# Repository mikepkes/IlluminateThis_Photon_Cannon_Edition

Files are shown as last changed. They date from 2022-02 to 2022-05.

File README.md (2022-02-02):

The Illuminate This "Photon Cannon Edition" is the 3rd production in the "Illuminate This" series.

Illuminate This boards are intended to be useful lighting boards for incorporating into your own projects.

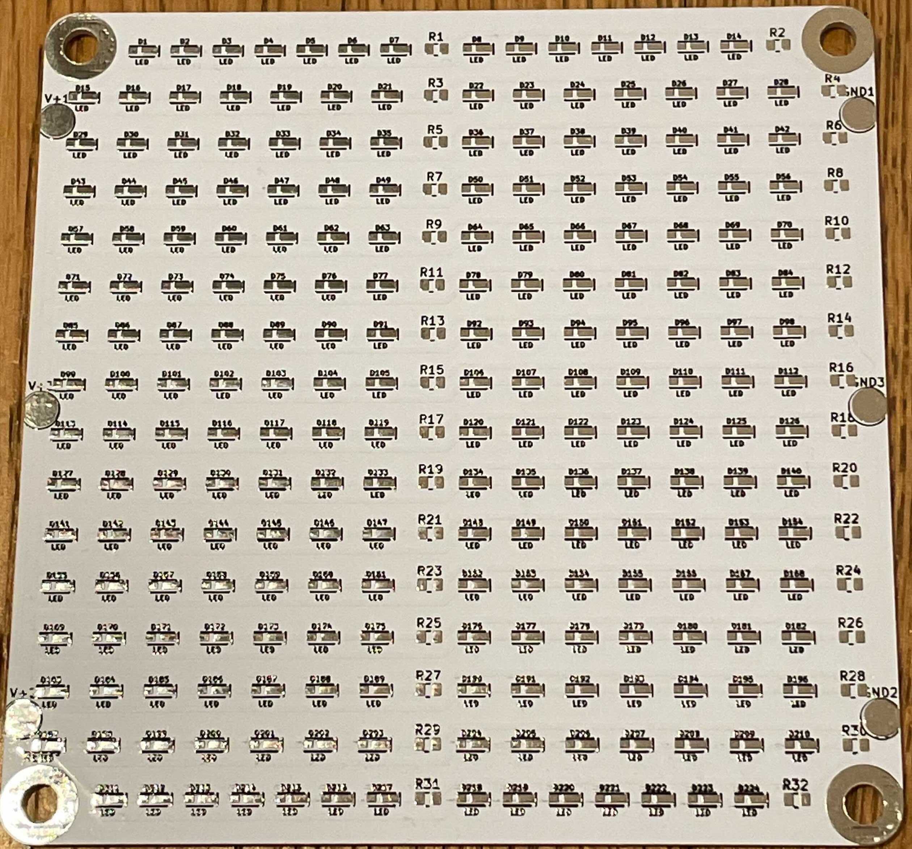
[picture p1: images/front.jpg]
Front PCB Render

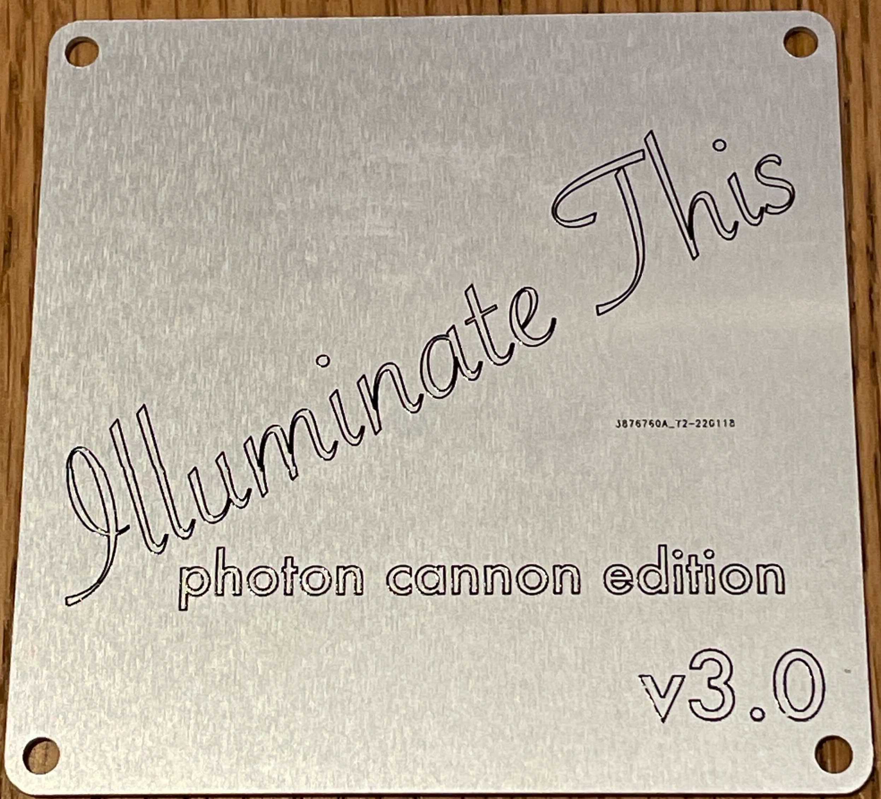
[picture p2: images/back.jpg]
Back PCB Render


Illuminate This boards are intended to provde:
* A large lighting area made of many LEDs
* Utilize component surplus at VHS
* Be easy to solder for people new to SMD components
* Customizable Lighitng, Remove Rows you don't want!

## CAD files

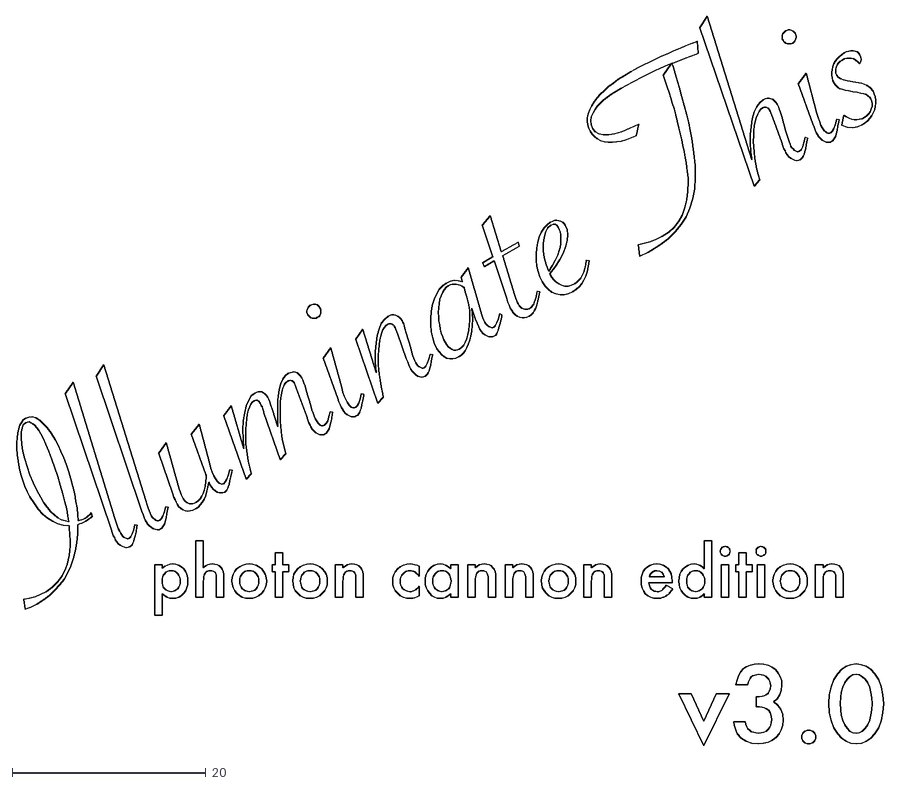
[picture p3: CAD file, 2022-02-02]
back_art.dxf
89.4 x 75.3

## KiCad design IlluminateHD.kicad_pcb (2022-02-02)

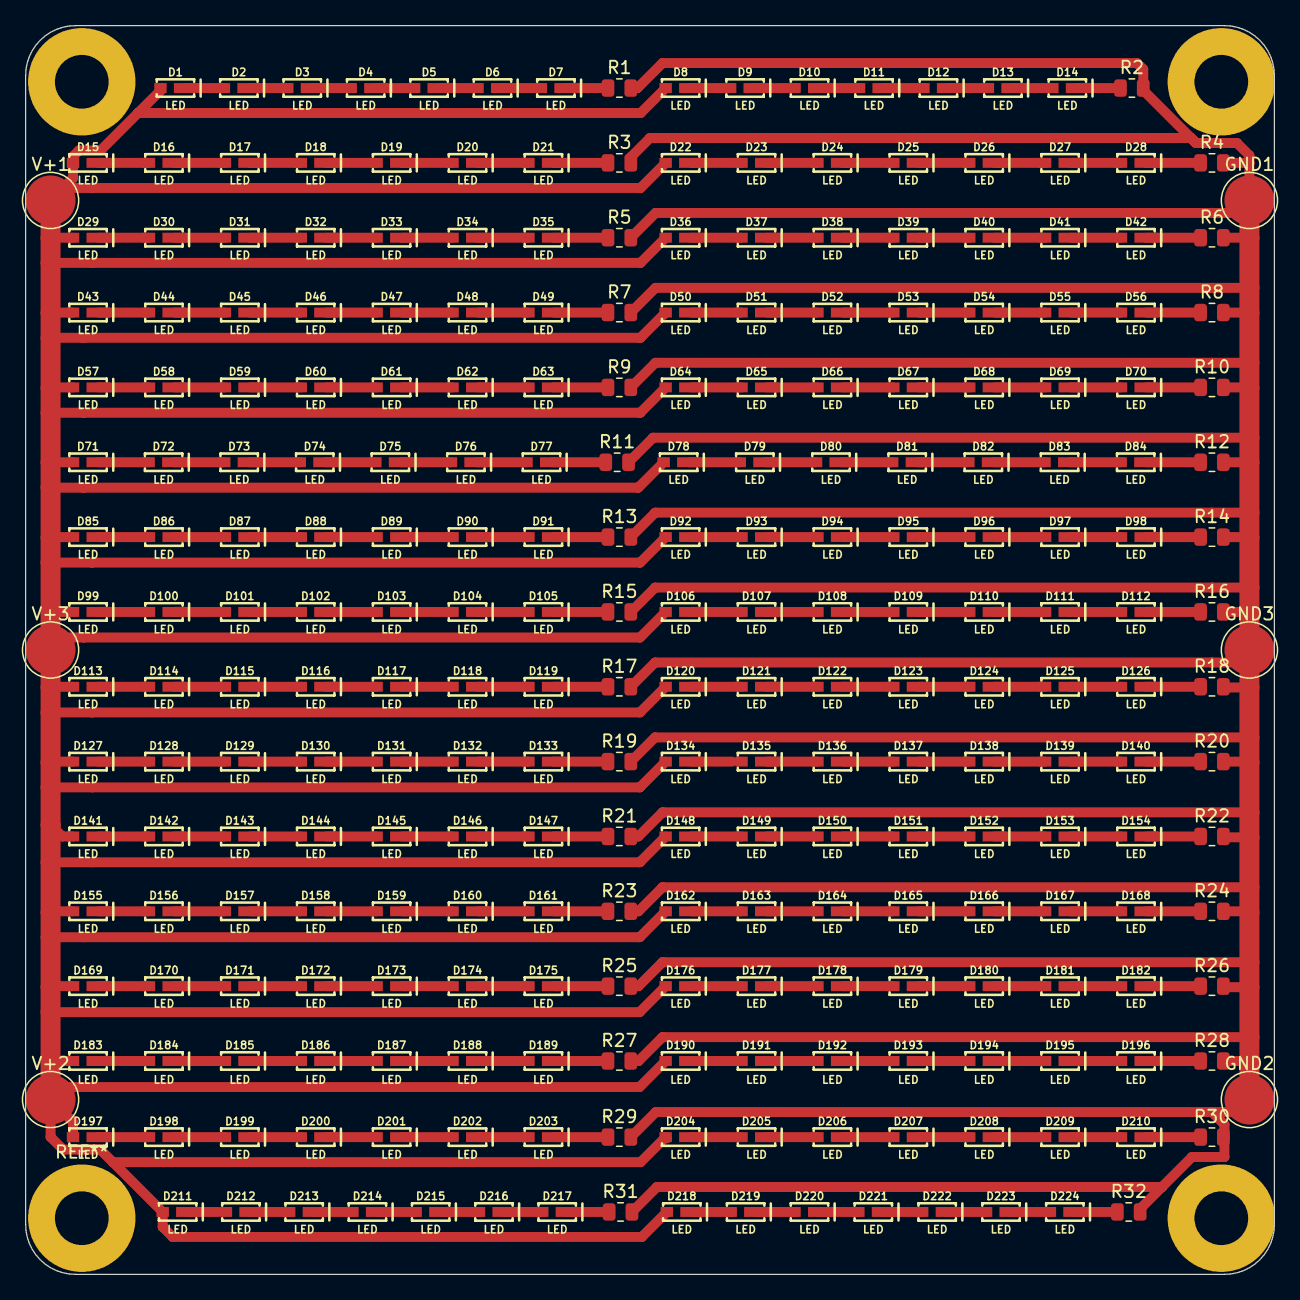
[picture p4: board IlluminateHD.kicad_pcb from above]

Board: 2 copper layers, 100.0 x 100.0 mm, 262 parts (0 on the bottom side), 226 nets.

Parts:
D1, D2, D3, D4, D5, D6, D7, D8, D9, D10, D11, D12, D13, D14, D15, D16, D17, D18, D19, D20, D21, D22, D23, D24, D25, D26, D27, D28, D29, D30, D31, D32, D33, D34, D35, D36, D37, D38, D39, D40, D41, D42, D43, D44, D45, D46, D47, D48, D49, D50, D51, D52, D53, D54, D55, D56, D57, D58, D59, D60, D61, D62, D63, D64, D65, D66, D67, D68, D69, D70, D71, D72, D73, D74, D75, D76, D77, D78, D79, D80, D81, D82, D83, D84, D85, D86, D87, D88, D89, D90, D91, D92, D93, D94, D95, D96, D97, D98, D99, D100, D101, D102, D103, D104, D105, D106, D107, D108, D109, D110, D111, D112, D113, D114, D115, D116, D117, D118, D119, D120, D121, D122, D123, D124, D125, D126, D127, D128, D129, D130, D131, D132, D133, D134, D135, D136, D137, D138, D139, D140, D141, D142, D143, D144, D145, D146, D147, D148, D149, D150, D151, D152, D153, D154, D155, D156, D157, D158, D159, D160, D161, D162, D163, D164, D165, D166, D167, D168, D169, D170, D171, D172, D173, D174, D175, D176, D177, D178, D179, D180, D181, D182, D183, D184, D185, D186, D187, D188, D189, D190, D191, D192, D193, D194, D195, D196, D197, D198, D199, D200, D201, D202, D203, D204, D205, D206, D207, D208, D209, D210, D211, D212, D213, D214, D215, D216, D217, D218, D219, D220, D221, D222, D223, D224: LED; SUPER_BRIGHT_SMD_LED_3014
GND1, GND2, GND3: TestPoint; TestPoint_Pad_D4.0mm
R1, R2, R3, R4, R5, R6, R7, R8, R9, R10, R11, R12, R13, R14, R15, R16, R17, R18, R19, R20, R21, R22, R23, R24, R25, R26, R27, R28, R29, R30, R31, R32: R_US; R_0805_2012Metric
V+1, V+2, V+3: TestPoint; TestPoint_Pad_D4.0mm

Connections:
+24V: D1.A, D8.A, D15.A, D22.A, D29.A, D36.A, D43.A, D50.A, D57.A, D64.A, D71.A, D78.A, D85.A, D92.A, D99.A, D106.A, D113.A, D120.A, D127.A, D134.A, D141.A, D148.A, D155.A, D162.A, D169.A, D176.A, D183.A, D190.A, D197.A, D204.A, D211.A, D218.A, V+1.1, V+2.1, V+3.1
GND: GND1.1, GND2.1, GND3.1, R1.2, R2.2, R3.2, R4.2, R5.2, R6.2, R7.2, R8.2, R9.2, R10.2, R11.2, R12.2, R13.2, R14.2, R15.2, R16.2, R17.2, R18.2, R19.2, R20.2, R21.2, R22.2, R23.2, R24.2, R25.2, R26.2, R27.2, R28.2, R29.2, R30.2, R31.2, R32.2
unnamed: D1.C, D2.A
unnamed: D2.C, D3.A
unnamed: D3.C, D4.A
unnamed: D4.C, D5.A
unnamed: D5.C, D6.A
unnamed: D6.C, D7.A
unnamed: D7.C, R1.1
unnamed: D8.C, D9.A
unnamed: D9.C, D10.A
unnamed: D10.C, D11.A
unnamed: D11.C, D12.A
unnamed: D12.C, D13.A
unnamed: D13.C, D14.A
unnamed: D14.C, R2.1
unnamed: D15.C, D16.A
unnamed: D16.C, D17.A
unnamed: D17.C, D18.A
unnamed: D18.C, D19.A
unnamed: D19.C, D20.A
unnamed: D20.C, D21.A
unnamed: D21.C, R3.1
unnamed: D22.C, D23.A
unnamed: D23.C, D24.A
unnamed: D24.C, D25.A
unnamed: D25.C, D26.A
unnamed: D26.C, D27.A
unnamed: D27.C, D28.A
unnamed: D28.C, R4.1
unnamed: D29.C, D30.A
unnamed: D30.C, D31.A
unnamed: D31.C, D32.A
unnamed: D32.C, D33.A
unnamed: D33.C, D34.A
unnamed: D34.C, D35.A
unnamed: D35.C, R5.1
unnamed: D36.C, D37.A
unnamed: D37.C, D38.A
unnamed: D38.C, D39.A
unnamed: D39.C, D40.A
unnamed: D40.C, D41.A
unnamed: D41.C, D42.A
unnamed: D42.C, R6.1
unnamed: D43.C, D44.A
unnamed: D44.C, D45.A
unnamed: D45.C, D46.A
unnamed: D46.C, D47.A
unnamed: D47.C, D48.A
unnamed: D48.C, D49.A
unnamed: D49.C, R7.1
unnamed: D50.C, D51.A
unnamed: D51.C, D52.A
unnamed: D52.C, D53.A
unnamed: D53.C, D54.A
unnamed: D54.C, D55.A
unnamed: D55.C, D56.A
unnamed: D56.C, R8.1
unnamed: D57.C, D58.A
unnamed: D58.C, D59.A
unnamed: D59.C, D60.A
unnamed: D60.C, D61.A
unnamed: D61.C, D62.A
unnamed: D62.C, D63.A
unnamed: D63.C, R9.1
unnamed: D64.C, D65.A
unnamed: D65.C, D66.A
unnamed: D66.C, D67.A
unnamed: D67.C, D68.A
unnamed: D68.C, D69.A
unnamed: D69.C, D70.A
unnamed: D70.C, R10.1
unnamed: D71.C, D72.A
unnamed: D72.C, D73.A
unnamed: D73.C, D74.A
unnamed: D74.C, D75.A
unnamed: D75.C, D76.A
unnamed: D76.C, D77.A
unnamed: D77.C, R11.1
unnamed: D78.C, D79.A
unnamed: D79.C, D80.A
unnamed: D80.C, D81.A
unnamed: D81.C, D82.A
unnamed: D82.C, D83.A
unnamed: D83.C, D84.A
unnamed: D84.C, R12.1
unnamed: D85.C, D86.A
unnamed: D86.C, D87.A
unnamed: D87.C, D88.A
unnamed: D88.C, D89.A
unnamed: D89.C, D90.A
unnamed: D90.C, D91.A
unnamed: D91.C, R13.1
unnamed: D92.C, D93.A
unnamed: D93.C, D94.A
unnamed: D94.C, D95.A
unnamed: D95.C, D96.A
unnamed: D96.C, D97.A
unnamed: D97.C, D98.A
unnamed: D98.C, R14.1
unnamed: D99.C, D100.A
unnamed: D100.C, D101.A
unnamed: D101.C, D102.A
unnamed: D102.C, D103.A
unnamed: D103.C, D104.A
unnamed: D104.C, D105.A
unnamed: D105.C, R15.1
unnamed: D106.C, D107.A
unnamed: D107.C, D108.A
unnamed: D108.C, D109.A
unnamed: D109.C, D110.A
unnamed: D110.C, D111.A
unnamed: D111.C, D112.A
unnamed: D112.C, R16.1
unnamed: D113.C, D114.A
unnamed: D114.C, D115.A
unnamed: D115.C, D116.A
unnamed: D116.C, D117.A
unnamed: D117.C, D118.A
unnamed: D118.C, D119.A
unnamed: D119.C, R17.1
unnamed: D120.C, D121.A
unnamed: D121.C, D122.A
unnamed: D122.C, D123.A
unnamed: D123.C, D124.A
unnamed: D124.C, D125.A
unnamed: D125.C, D126.A
unnamed: D126.C, R18.1
unnamed: D127.C, D128.A
unnamed: D128.C, D129.A
unnamed: D129.C, D130.A
unnamed: D130.C, D131.A
unnamed: D131.C, D132.A
unnamed: D132.C, D133.A
unnamed: D133.C, R19.1
unnamed: D134.C, D135.A
unnamed: D135.C, D136.A
unnamed: D136.C, D137.A
unnamed: D137.C, D138.A
unnamed: D138.C, D139.A
unnamed: D139.C, D140.A
unnamed: D140.C, R20.1
unnamed: D141.C, D142.A
unnamed: D142.C, D143.A
unnamed: D143.C, D144.A
unnamed: D144.C, D145.A
unnamed: D145.C, D146.A
unnamed: D146.C, D147.A
unnamed: D147.C, R21.1
unnamed: D148.C, D149.A
unnamed: D149.C, D150.A
unnamed: D150.C, D151.A
unnamed: D151.C, D152.A
unnamed: D152.C, D153.A
unnamed: D153.C, D154.A
unnamed: D154.C, R22.1
unnamed: D155.C, D156.A
unnamed: D156.C, D157.A
unnamed: D157.C, D158.A
unnamed: D158.C, D159.A
unnamed: D159.C, D160.A
unnamed: D160.C, D161.A
unnamed: D161.C, R23.1
unnamed: D162.C, D163.A
unnamed: D163.C, D164.A
unnamed: D164.C, D165.A
unnamed: D165.C, D166.A
unnamed: D166.C, D167.A
unnamed: D167.C, D168.A
unnamed: D168.C, R24.1
unnamed: D169.C, D170.A
unnamed: D170.C, D171.A
unnamed: D171.C, D172.A
unnamed: D172.C, D173.A
unnamed: D173.C, D174.A
unnamed: D174.C, D175.A
unnamed: D175.C, R25.1
unnamed: D176.C, D177.A
unnamed: D177.C, D178.A
unnamed: D178.C, D179.A
unnamed: D179.C, D180.A
unnamed: D180.C, D181.A
unnamed: D181.C, D182.A
unnamed: D182.C, R26.1
unnamed: D183.C, D184.A
unnamed: D184.C, D185.A
unnamed: D185.C, D186.A
unnamed: D186.C, D187.A
unnamed: D187.C, D188.A
unnamed: D188.C, D189.A
unnamed: D189.C, R27.1
unnamed: D190.C, D191.A
unnamed: D191.C, D192.A
unnamed: D192.C, D193.A
unnamed: D193.C, D194.A
unnamed: D194.C, D195.A
unnamed: D195.C, D196.A
unnamed: D196.C, R28.1
unnamed: D197.C, D198.A
unnamed: D198.C, D199.A
unnamed: D199.C, D200.A
unnamed: D200.C, D201.A
unnamed: D201.C, D202.A
unnamed: D202.C, D203.A
unnamed: D203.C, R29.1
unnamed: D204.C, D205.A
unnamed: D205.C, D206.A
unnamed: D206.C, D207.A
unnamed: D207.C, D208.A
unnamed: D208.C, D209.A
unnamed: D209.C, D210.A
unnamed: D210.C, R30.1
unnamed: D211.C, D212.A
unnamed: D212.C, D213.A
unnamed: D213.C, D214.A
unnamed: D214.C, D215.A
unnamed: D215.C, D216.A
unnamed: D216.C, D217.A
unnamed: D217.C, R31.1
unnamed: D218.C, D219.A
unnamed: D219.C, D220.A
unnamed: D220.C, D221.A
unnamed: D221.C, D222.A
unnamed: D222.C, D223.A
unnamed: D223.C, D224.A
unnamed: D224.C, R32.1

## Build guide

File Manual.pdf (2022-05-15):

# Illuminate This

# Photon Cannon Edition (v3.0)

Welcome to the instruction manual for the Illuminate This: Photon Cannon Edition, the third edition of the Illuminate This board.

The “Illuminate This” series was born at the Vancouver Hackspace, when millions upon millions of white SMD LEDs were donated and there was no plan for them. This board provides a nice way of creating area-like lights that can be used as back-lighting, or just really really big flat bulbs.
The Illuminate This: Photon Cannon Edition tech specs are as follows:

## Building the Photon Cannon

It is recommended to use the provided solder stencil to build the Illuminate This boards and use the solder oven; it is not recommended to hand-solder LEDs, especially on aluminum boards, as it will be exceedingly difficult to not damage the LEDs while getting the pad hot enough to flow.

Name | The Illuminate This: Photon Cannon Edition
Board Version | v3.0
Width | 100mm
Height | 100mm
Supply Voltage | 24v
Supply Maximum Current | 6.2 Amps (at 20ma configuration, fully populated)
LED Grouping | 7 LEDs, 1 Current Limiting Resistor
Maximum LEDs | 224
Board Material | Aluminum or FR4
Mounting Holes | M4 x 4
LED Form Factor | 3014 SMD
Resistor Form Factor | 0805 SMD

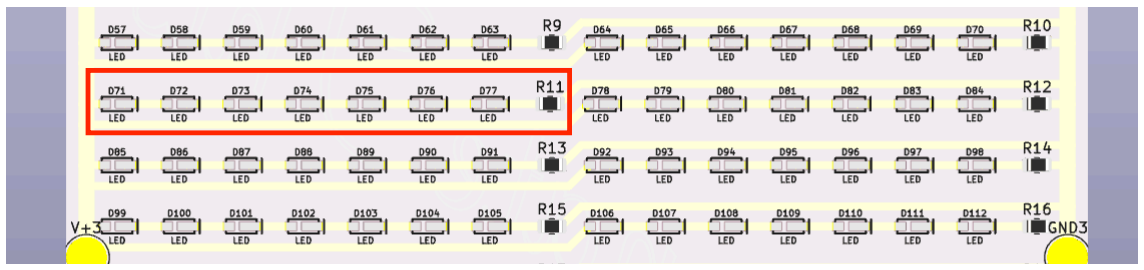
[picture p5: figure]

The Illiminate This boards are divided by rows and columns. The Photon Cannon is comprised of 2 columns and 16 rows. When populating the board, you must fill out all the components in one cell. For instance, you can fill out only half a row, but all 8 components (7 LEDs and one Resistor) must be populated on one side. An example of a single “cell” is illustrated below: Once the board has been populated and baked, Ground and V+ leads can be attached. Using flux and pre-tinning is recommended; with aluminum boards, some pre-heating may be useful to ensure the pad can reach solder flow temperature.

Once soldered, glue or epoxy on top of leads is recommended to help prevent desoldering, ensure proper strain relief is provided.

LED and Resistor Values:

It is recommended to use https://ledcalculator.net/ to size your LEDs, desired current per LED, to determine your resistor value.
